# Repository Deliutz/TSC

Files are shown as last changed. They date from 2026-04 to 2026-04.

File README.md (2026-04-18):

# InkTime Smartwatch Project

Proiect hardware pentru realizarea unui smartwatch open-source low-cost, bazat pe microcontrollerul **Nordic nRF52840**, proiectat în **Autodesk Fusion 360 Electronics**.

---

# Diagrama bloc

```text
Baterie LiPo
    |
    v
+------------------+
|   BQ25180YBGR    |
| Charger / PMIC   |
+------------------+
    |
    v
+------------------+
|    RT6160AWSC    |
| Buck-Boost 3.3V  |
+------------------+
    |
    v
+------------------+
|    nRF52840      |
|   MCU + BLE      |
+------------------+
   |      |      |      |      |
   |      |      |      |      |
   |      |      |      |      +-------------------+
   |      |      |      |                          |
   |      |      |      v                          v
   |      |      |  +---------+              +-----------+
   |      |      |  | Buttons |              | TC2030    |
   |      |      |  | 3x GPIO |              | SWD Debug |
   |      |      |  +---------+              +-----------+
   |      |      |
   |      |      +-------------------+
   |      |                          |
   |      v                          v
   |  +-----------+            +------------+
   |  | DRV2605   |----------->| Vibra motor|
   |  | Haptic IC |            +------------+
   |  +-----------+
   |
   +---------------------+
   |                     |
   v                     v
+---------+         +-----------+
| BMA421  |         | MAX17048  |
| IMU     |         | Fuel Gauge|
+---------+         +-----------+
   ^                     ^
   |                     |
   +--------- I2C -------+

```

---

# Bill of Materials (BOM)

| Componenta | Cod | Rol | Interfata |
|---|---|---|---|
| NRF52840_QF | U1 | Microcontroller principal + BLE | SPI / I2C / GPIO |
| BQ25180YBGR | IC1 | Incarcare baterie LiPo / power management | Power / I2C |
| RT6160AWSC | IC9 | Convertor buck-boost 3.3V | Power |
| BMA421 | IC3 | Accelerometru / IMU | I2C |
| DRV2605YZFR | IC2 | Driver feedback haptic | I2C / GPIO |
| MAX17048G+T10 | U3 | Fuel gauge baterie | I2C |
| KH-TYPE-C-16P | J4 | Conector USB-C | USB |
| USBLC6-2SC6Y | D3 | Protectie ESD USB | USB |
| 503480-2400 | J2 | Conector display e-paper | SPI |
| 2450AT18B100E | ANT1 | Antena 2.4 GHz BLE | RF |
| TC2030-IDC | J1 | Conector debugging SWD | SWD |
| SW_UP / SW_ENT / SW_DN | SW_UP, SW_ENT, SW_DN | Input utilizator | GPIO |
| X1 | X1 | Cristal de mare frecventa pentru nRF52840 | Clock |
| X2 32.768kHz | X2 | Cristal RTC / low power clock | Clock |
| SI1308EDL-T1-GE3 | Q3 | MOSFET pentru comutare alimentare | Power / GPIO |
| Q1 | Q1 | MOSFET pentru power switching | Power |
| FTC252012SR47MBCA | L7 | Inductor pentru regulatorul de tensiune | Power |
| MBR0530 | D2, D4, D5 | Diode Schottky pentru protectie / redresare | Power |
| TP_* | TP_3.3V, TP_3V3, TP_BAT_GND, TP_GND, TP_ON, TP_OP, TP_RESET, TP_SCL, TP_SDA, TP_SWDCLK, TP_SWDIO, TP_SWO, TP_VBAT, TP_VREG | Test pads pentru validare si debugging | Test / Debug |

---

# Funcționalitate hardware
Designul este construit în jurul microcontrollerului **nRF52840**, responsabil de:
- comunicația Bluetooth Low Energy;
- citirea senzorilor;
- controlul display-ului e-paper;
- gestionarea butoanelor;
- controlul feedback-ului haptic;
- monitorizarea bateriei.

## Alimentare
- **BQ25180** gestionează încărcarea bateriei LiPo;
- **RT6160** generează tensiunea stabilă de **3.3V**;
- **MAX17048** monitorizează nivelul bateriei.

## Senzori și periferice
- **BMA423** este conectat prin **I2C**;
- display-ul e-paper este conectat prin conectorul FPC;
- **DRV2605** comandă motorul de vibrații;
- USB-C este folosit pentru alimentare și debugging.

---

# Utilizarea pinilor nRF52840
## Magistrală I2C
- SDA → IMU + Fuel Gauge
- SCL → IMU + Fuel Gauge

## SWD
- SWDIO
- SWDCLK
- SWO
- RESET

## GPIO
- Buton UP
- Buton ENTER
- Buton DOWN
- semnale control display
- semnal driver haptic

## SPI
- semnale rutate către conectorul display-ului e-paper

---

# Proces de proiectare

## 1. Schematic
În prima etapă am realizat schema electrică pornind de la modelul oferit pe OCW și folosind exclusiv biblioteca pusă la dispoziție.

Am implementat blocurile:
- LiPo Charger
- DC/DC
- IMU
- SWD
- E-Paper Driver
- Fuel Gauge
- Haptic Driver
- Buttons
- USB-C + ESD

În timpul realizării schemei:
- am modificat valorile componentelor pasive;
- am adăugat condensatoare de decuplare;
- am etichetat semnalele importante;
- am separat schematicul pe blocuri funcționale.

---

## 2. PCB Design
PCB-ul a fost realizat pe baza dimensiunilor mecanice recomandate.

Etapele principale:
- placement TOP pentru componentele critice;
- amplasarea componentelor pasive lângă pinii de alimentare;
- rutare pe mai multe straturi;
- plane dedicate de GND;
- păstrarea zonei antenei liberă;
- alinierea USB-C și a butoanelor cu carcasa.

La final am rulat DRC și am corectat erorile principale.

---

## 3. Model 3D
Modelul 3D include:
- PCB
- baterie
- display
- carcasă

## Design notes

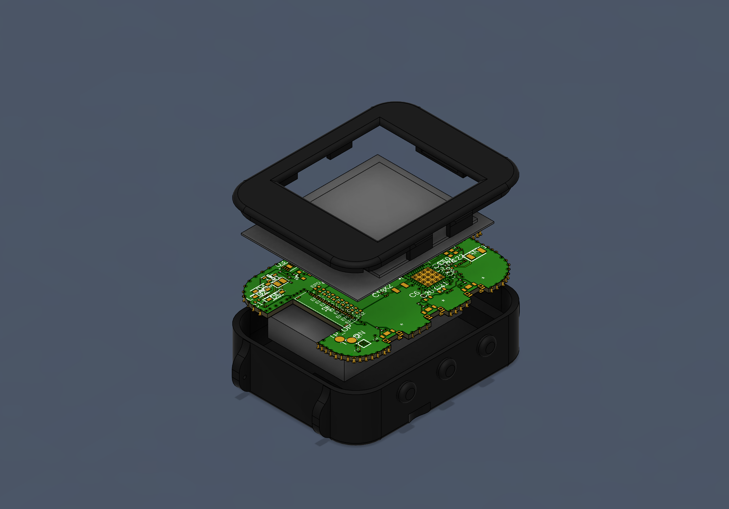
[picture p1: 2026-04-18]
Images/explozie_finala.png

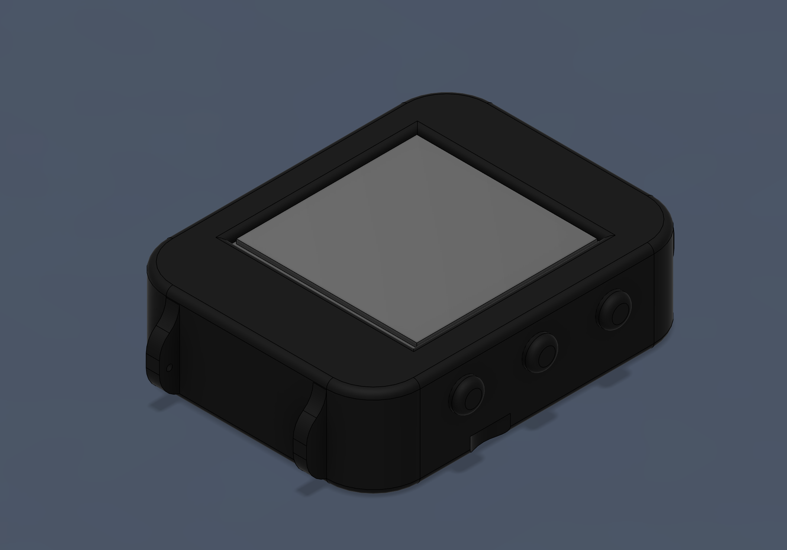
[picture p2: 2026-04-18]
Images/poza_carcasa_finala.png

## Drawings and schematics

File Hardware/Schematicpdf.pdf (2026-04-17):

# LiPo Charger

# DC/DC

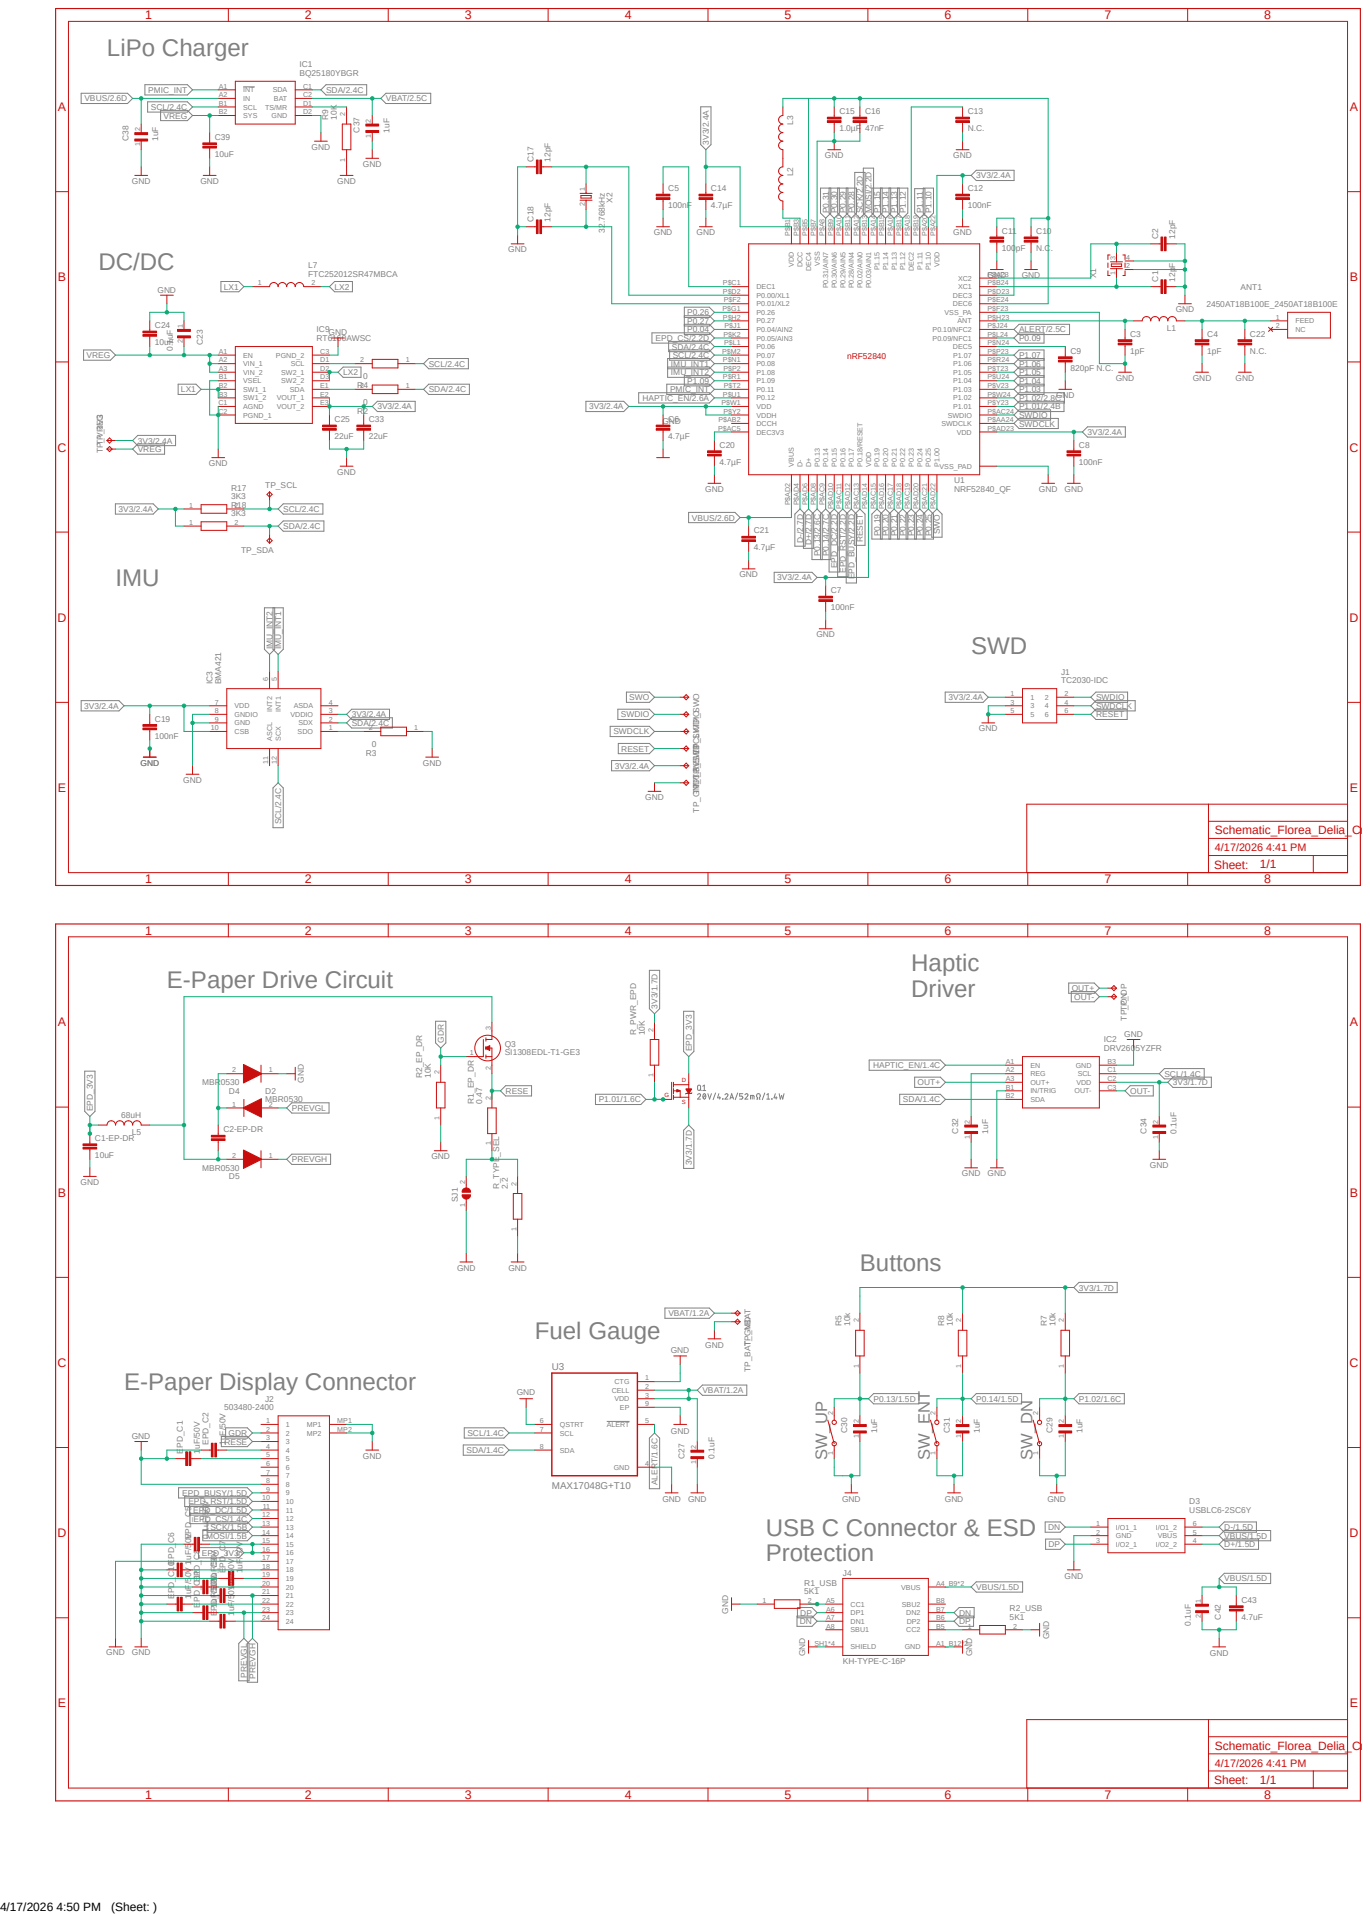
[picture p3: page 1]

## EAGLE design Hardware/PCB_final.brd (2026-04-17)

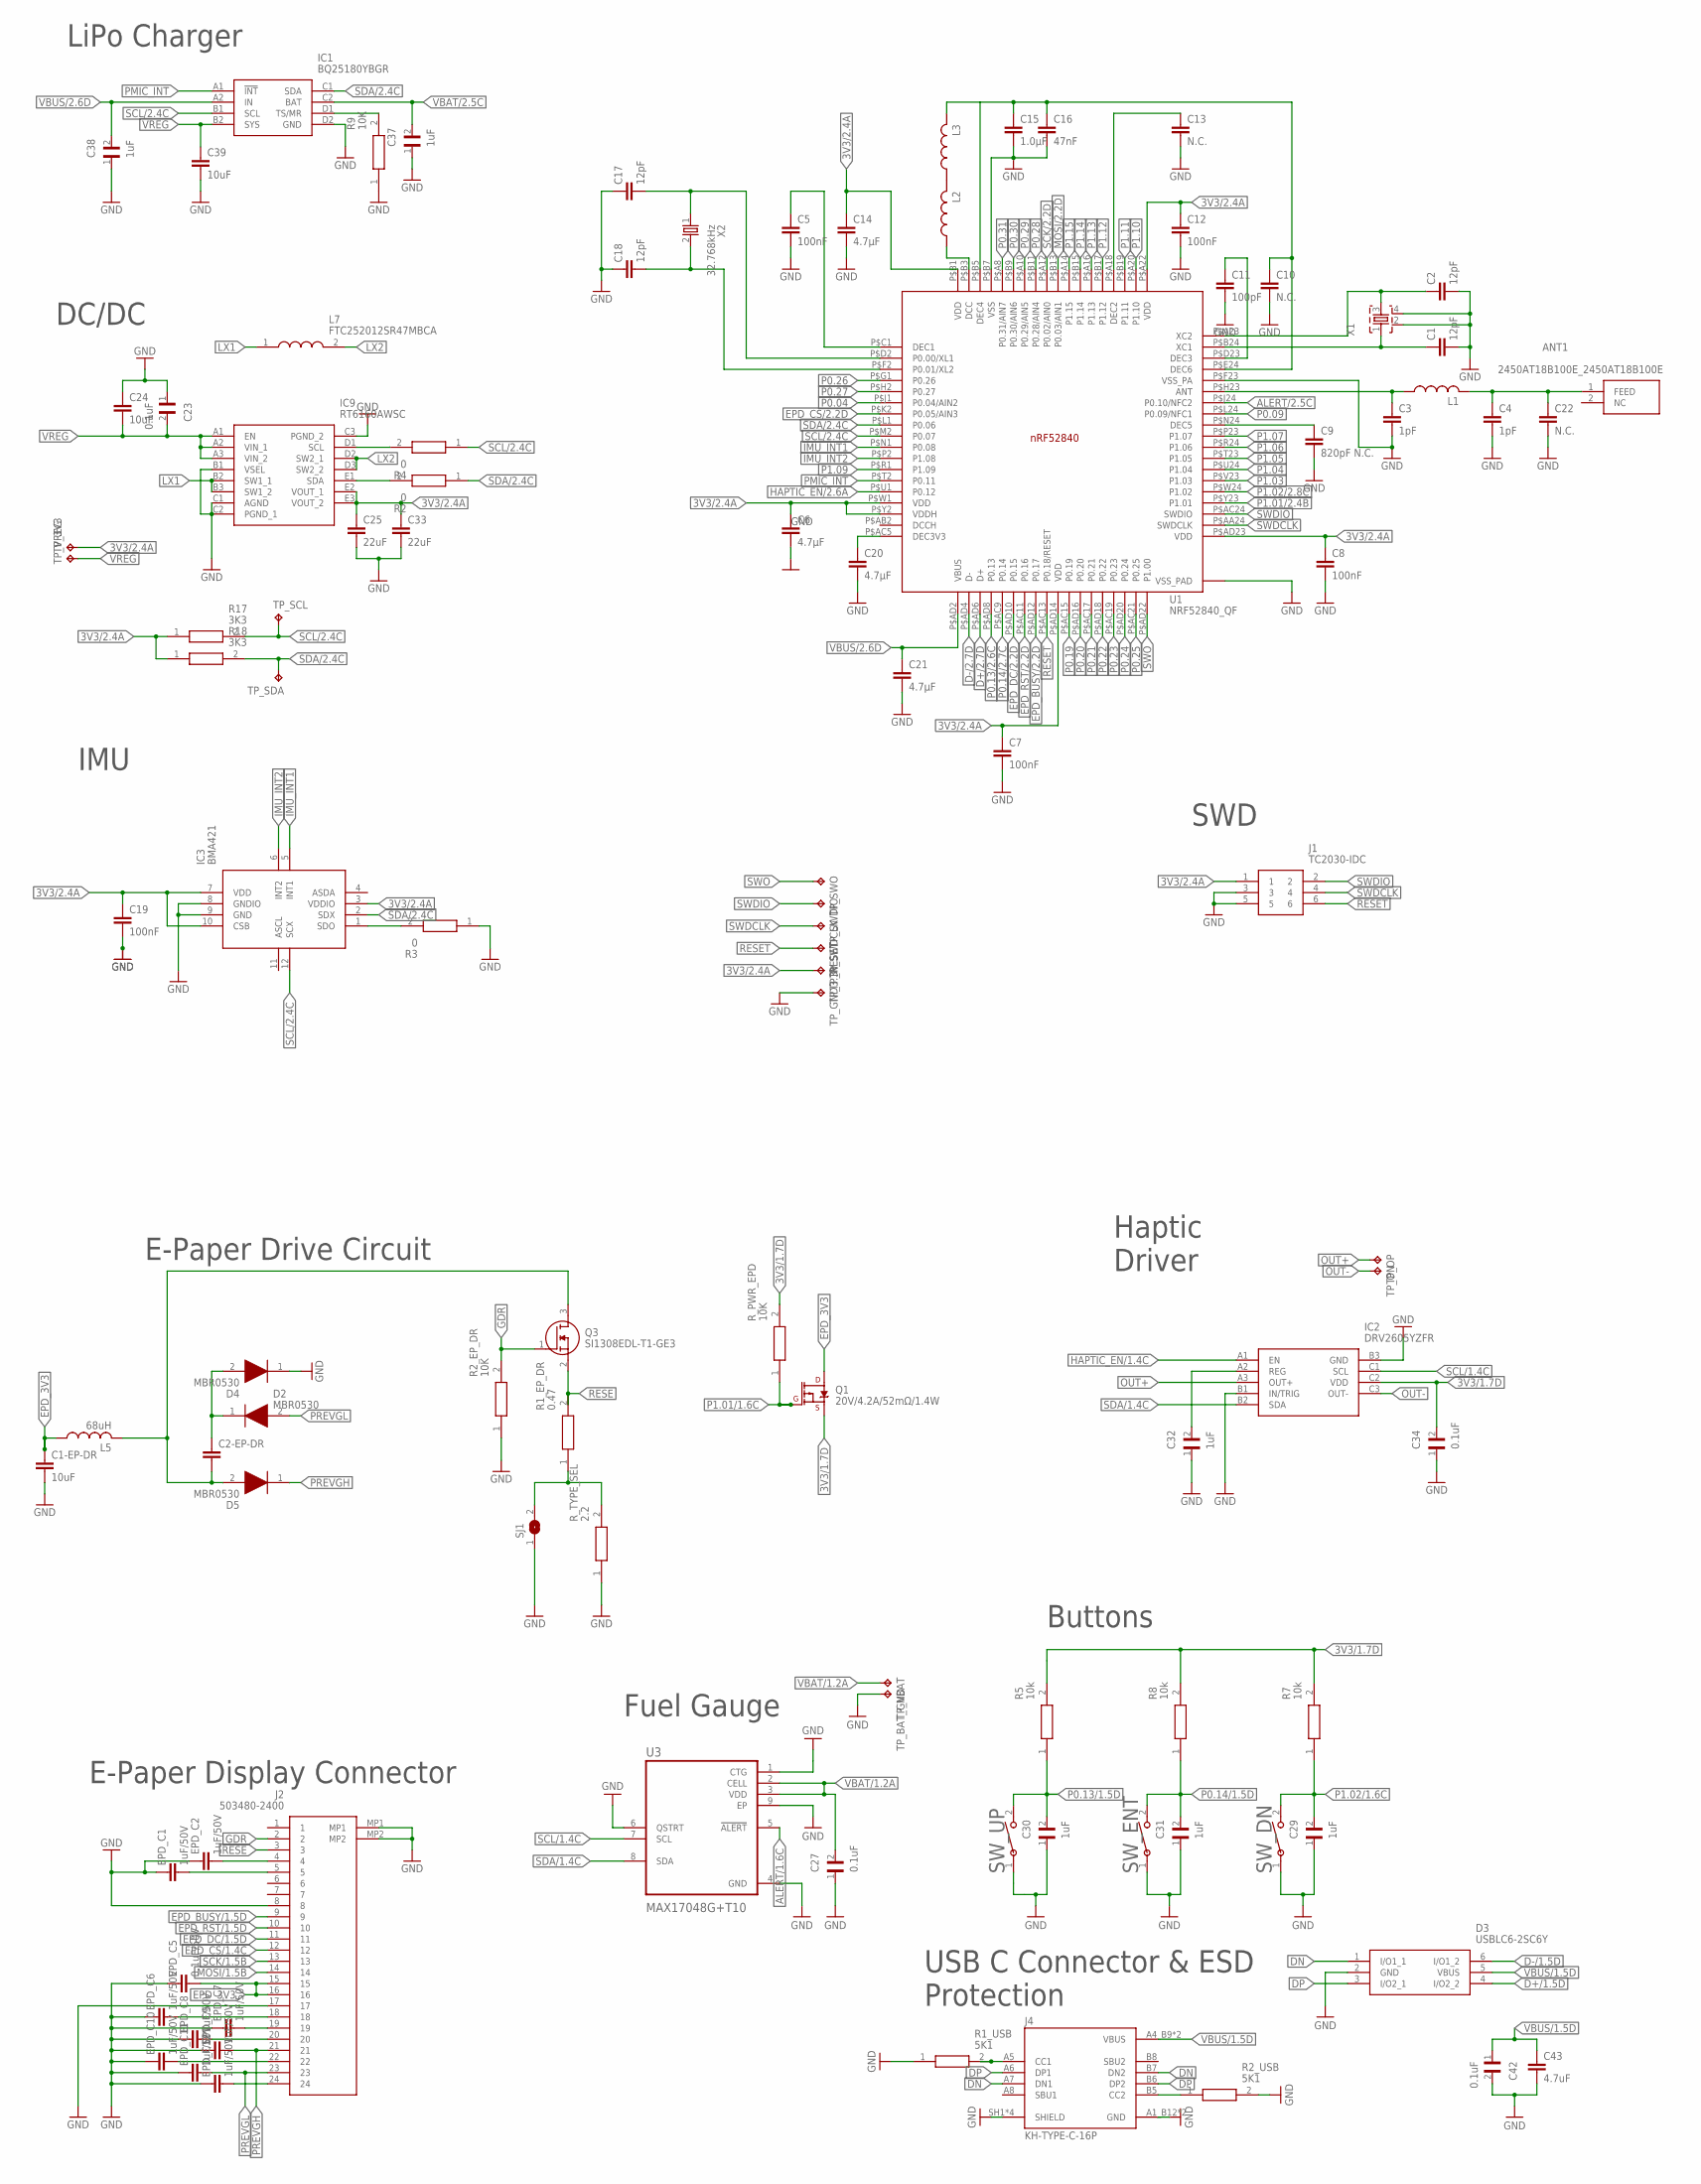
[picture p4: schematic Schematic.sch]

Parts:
ANT1: 2450AT18B100E_2450AT18B100E; 2450AT18B100E_ANTC3216X140N
C1, C2, C17, C18: 12pF; NORDIC_NRF_3_RESC0201_L
C1-EP-DR, C24, C39: 10uF; NORDIC_NRF_3_RESC0201_L
C2-EP-DR: NORDIC_NRF_3_CAPACITOR_0201_L; NORDIC_NRF_3_RESC0201_L
C3, C4: 1pF; NORDIC_NRF_3_RESC0201_L
C5, C7, C8, C12, C19: 100nF; NORDIC_NRF_3_RESC0201_L
C6: 4.7µF; NORDIC_NRF_3_RESC0201_L
C9: 820pF N.C.; NORDIC_NRF_3_RESC0201_L
C10, C13, C22: N.C.; NORDIC_NRF_3_RESC0201_L
C11: 100pF; NORDIC_NRF_3_RESC0201_L
C14, C20, C21: 4.7µF; ESP32_C6_LIBRARY_1_ESP32_WROVER_EAGLE-LTSPICE_C0402
C15: 1.0µF; NORDIC_NRF_3_RESC0201_L
C16: 47nF; NORDIC_NRF_3_RESC0201_L
C23, C34: 0.1uF; GRM011R60J152KE01L_2_CAPC0201X13N
C25, C33: 22uF; NORDIC_NRF_3_RESC0201_L
C27, C42: 0.1uF; GRM011R60J152KE01L_1_0201
C29, C30, C31: 1uF; GRM011R60J152KE01L_1_0201
C32, C37, C38: 1uF; GRM011R60J152KE01L_2_CAPC0201X13N
C43: 4.7uF; NORDIC_NRF_3_RESC0201_L
D2, D4, D5: MBR0530; ESP32_C6_LIBRARY_5_SOD3716X135N
D3: USBLC6-2SC6Y; ESP32_C6_LIBRARY_3_SOT95P280X145-6N
EPD_C1, EPD_C2, EPD_C6, EPD_C7, EPD_C8, EPD_C9, EPD_C10, EPD_C11, EPD_C12: 1uF/50V; PERFECT_0402_0402
EPD_C5: 0.1uF/50V; PERFECT_0402_0402
IC1: BQ25180YBGR; BQ25180YBGR_BGA8C40P2X4_100X155X50
IC2: DRV2605YZFR; DRV2605YZFR_BGA9C50P3X3_144X144X62
IC3: BMA421; BMA423_BMA423
IC9: RT6160AWSC; RT6160AWSC_BGA15C40P3X5_140X230X60
J1: TC2030-IDC; TC2030-IDC_TC2030IDC
J2: 503480-2400; 503480-2400_5034802400
J4: KH-TYPE-C-16P; KH-TYPE-C-16P_KINGHELM_KH-TYPE-C-16P
L1, L2, L3: NORDIC_NRF_2_INDUCTOR_0402_L; NORDIC_NRF_2_RESC0402_L
L5: 68uH; NORDIC_NRF_2_RESC0402_L
L7: FTC252012SR47MBCA; MLP2016SR47MT0S1_INDC2016X100N
Q1: 20V/4.2A/52mΩ/1.4W; ESP32_C6_LIBRARY_4_ESP32_C6_LIBRARY_4_ESP32_C6_LIBRARY_4_ES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
Q3: SI1308EDL-T1-GE3; ESP32_C6_LIBRARY_6_SOT65P210X110-3N
R1_EP_DR: 0.47; ERA-1AEB3401C_0201
R1_USB, R2_USB: 5K1; CPF0201D7K68C1_0201
R2, R4: 0; ERA-1AEB3401C_0201
R2_EP_DR, R9: 10K; ERA-1AEB3401C_0201
R3: 0; CPF0201D7K68C1_0201
R5, R7, R8: 10k; CPF0201D7K68C1_0201
R17, R18: 3K3; ERA-1AEB3401C_0201
R_PWR_EPD: 10K; ERA-1AEB3401C_0201
R_TYPE_SEL: 2.2; ERA-1AEB3401C_0201
SJ1: ESP32_C6_LIBRARY_7_JUMPER_SJ
SW_DN: 2025-10-22_07-23-44_LIBRARY_EVP-AKE31ASW_EVP-AKE3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; 2025-10-22_07-23-44_LIBRARY_SW_EVP-AKE31A_PAN
SW_ENT: 2025-10-22_07-23-44_LIBRARY_EVP-AKE31ASW_EVP-AKE3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; 2025-10-22_07-23-44_LIBRARY_SW_EVP-AKE31A_PAN
SW_UP: 2025-10-22_07-23-44_LIBRARY_EVP-AKE31ASW_EVP-AKE3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; 2025-10-22_07-23-44_LIBRARY_SW_EVP-AKE31A_PAN
TP_3.3V, TP_3V3: HECTOR_WATCH_1_TPTP20R; HECTOR_WATCH_1_TP20R
TP_BAT_GND: HECTOR_WATCH_1_TPTP20R; HECTOR_WATCH_1_TP20R
TP_GND: HECTOR_WATCH_1_TPTP20R; HECTOR_WATCH_1_TP20R
TP_ON: HECTOR_WATCH_1_TPTP20R; HECTOR_WATCH_1_TP20R
TP_OP: HECTOR_WATCH_1_TPTP20R; HECTOR_WATCH_1_TP20R
TP_RESET: HECTOR_WATCH_1_TPTP20R; HECTOR_WATCH_1_TP20R
TP_SCL: HECTOR_WATCH_1_TPTP20R; HECTOR_WATCH_1_TP20R
TP_SDA: HECTOR_WATCH_1_TPTP20R; HECTOR_WATCH_1_TP20R
TP_SWDCLK: HECTOR_WATCH_1_TPTP20R; HECTOR_WATCH_1_TP20R
TP_SWDIO: HECTOR_WATCH_1_TPTP20R; HECTOR_WATCH_1_TP20R
TP_SWO: HECTOR_WATCH_1_TPTP20R; HECTOR_WATCH_1_TP20R
TP_VBAT: HECTOR_WATCH_1_TPTP20R; HECTOR_WATCH_1_TP20R
TP_VREG: HECTOR_WATCH_1_TPTP20R; HECTOR_WATCH_1_TP20R
U1: NRF52840_QF; NORDIC_NRF_4_AQFN50P700X700X85_HS-74N
U3: MAX17048G+T10; ESP32_C6_LIBRARY_SON50P200X200X80-9N
X1: NORDIC_NRF_XTAL_32MHZ; NORDIC_NRF_BT-XTAL_2016_N
X2: 32.768kHz; NORDIC_NRF_1_XTAL_3215_N

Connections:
3V3/1.7D: C34.2, IC2.C2 (VDD), Q1.2 (S), R5.2, R7.2, R8.2, R_PWR_EPD.2
3V3/2.4A: C6.1, C7.1, C8.1, C12.1, C14.1, C19.1, C25.1, C33.1, IC3.3 (VDDIO), IC3.7 (VDD), IC3.10 (CSB), IC9.E2 (VOUT_1), IC9.E3 (VOUT_2), J1.1, R17.1, R18.1, TP_3.3V.TP, TP_3V3.TP, U1.P$A22 (VDD), U1.P$AD14 (VDD), U1.P$AD23 (VDD), U1.P$B1 (VDD), U1.P$W1 (VDD), U1.P$Y2 (VDDH)
ALERT/1.6C: U3.5 (!ALERT)
ALERT/2.5C: U1.P$J24 (P0.10/NFC2)
D+/1.5D: D3.4 (I/O2_2)
D+/2.7D: U1.P$AD6 (D+)
D-/1.5D: D3.6 (I/O1_2)
D-/2.7D: U1.P$AD4 (D-)
DN: D3.1 (I/O1_1), J4.A7 (DN1), J4.B7 (DN2)
DP: D3.3 (I/O2_1), J4.A6 (DP1), J4.B6 (DP2)
EPD_3V3: C1-EP-DR.1, EPD_C5.2, J2.15, J2.16, L5.1, Q1.3 (D)
EPD_BUSY/1.5D: J2.9
EPD_BUSY/2.2D: U1.P$AD12 (P0.17)
EPD_CS/1.4C: J2.12
EPD_CS/2.2D: U1.P$K2 (P0.05/AIN3)
EPD_DC/1.5D: J2.11
EPD_DC/2.2D: U1.P$AD10 (P0.15)
EPD_RST/1.5D: J2.10
EPD_RST/2.2D: U1.P$AC11 (P0.16)
GDR: J2.2, Q3.1 (G), R2_EP_DR.2
GND: C1.2, C1-EP-DR.2, C2.2, C3.2, C4.2, C5.2, C6.2, C7.2, C8.2, C9.2, C10.2, C11.2, C12.2, C13.2, C14.2, C15.2, C16.2, C17.1, C18.1, C19.2, C20.2, C21.2, C22.2, C23.1, C24.1, C25.2, C27.1, C29.1, C30.1, C31.1, C32.1, C33.2, C34.1, C37.1, C38.1, C39.2, C42.2, C43.2, D3.2 (GND), D4.1 (K), EPD_C1.1, EPD_C2.1, EPD_C5.1, EPD_C6.1, EPD_C7.1, EPD_C8.1, EPD_C9.1, EPD_C10.1, EPD_C11.1, EPD_C12.1, IC1.D2 (GND), IC2.B1 (IN/TRIG), IC2.B3 (GND), IC3.8 (GNDIO), IC3.9 (GND), IC9.B1 (VSEL), IC9.C1 (AGND), IC9.C2 (PGND_1), IC9.C3 (PGND_2), J1.3, J1.5, J2.8, J2.17, J2.MP1, J2.MP2, J4.A1_B12 (GND), J4.A12_B1 (GND), J4.SH1 (SHIELD), J4.SH2 (SHIELD), J4.SH3 (SHIELD), J4.SH4 (SHIELD), R1_USB.1, R2_EP_DR.1, R2_USB.2, R3.1, R9.1, R_TYPE_SEL.1, SJ1.1, SW_DN.1, SW_ENT.1, SW_UP.1, TP_BAT_GND.TP, TP_GND.TP, U1.P$74 (VSS_PAD), U1.P$75 (VSS_PAD), U1.P$76 (VSS_PAD), U1.P$77 (VSS_PAD), U1.P$78 (VSS_PAD), U1.P$79 (VSS_PAD), U1.P$80 (VSS_PAD), U1.P$81 (VSS_PAD), U1.P$82 (VSS_PAD), U1.P$83 (VSS_PAD), U1.P$84 (VSS_PAD), U1.P$85 (VSS_PAD), U1.P$86 (VSS_PAD), U1.P$87 (VSS_PAD), U1.P$88 (VSS_PAD), U1.P$89 (VSS_PAD), U1.P$90 (VSS_PAD), U1.P$B7 (VSS), U1.P$F23 (VSS_PA), U3.1 (CTG), U3.4 (GND), U3.6 (QSTRT), U3.9 (EP), X1.2, X1.4
HAPTIC_EN/1.4C: IC2.A1 (EN)
HAPTIC_EN/2.6A: U1.P$U1 (P0.12)
IMU_INT1: IC3.5 (INT1), U1.P$N1 (P0.08)
IMU_INT2: IC3.6 (INT2), U1.P$P2 (P1.08)
LX1: IC9.B2 (SW1_1), IC9.B3 (SW1_2), L7.1
LX2: IC9.D2 (SW2_1), IC9.D3 (SW2_2), L7.2
MOSI/1.5B: J2.14
MOSI/2.2D: U1.P$B13 (P0.03/AIN1)
unnamed: IC1.D1 (TS/MR), R9.2
unnamed: L2.2, L3.1
unnamed: C10.1, C15.1, C16.1, L3.2, U1.P$E24 (DEC6)
unnamed: ANT1.1 (FEED), C4.1, C22.1, L1.2
unnamed: IC9.D1 (SCL), R4.2
unnamed: C2-EP-DR.2, D5.2 (A), L5.2, Q3.3 (D)
unnamed: IC9.E1 (SDA), R2.2
unnamed: C2-EP-DR.1, D2.1 (K), D4.2 (A)
unnamed: IC3.1 (SDO), R3.2
unnamed: EPD_C2.2, J2.4
unnamed: C32.2, IC2.A2 (REG)
unnamed: EPD_C1.2, J2.5
unnamed: C20.1, U1.P$AC5 (DEC3V3)
unnamed: C5.1, U1.P$C1 (DEC1)
unnamed: C17.2, U1.P$D2 (P0.00/XL1), X2.1
unnamed: C18.2, U1.P$F2 (P0.01/XL2), X2.2
unnamed: R1_EP_DR.1, R_TYPE_SEL.2, SJ1.2
unnamed: L2.1, U1.P$B3 (DCC)
unnamed: J4.A5 (CC1), R1_USB.2
unnamed: C3.1, L1.1, U1.P$H23 (ANT)
unnamed: C9.1, U1.P$N24 (DEC5)
unnamed: C1.1, U1.P$B24 (XC1), X1.1
unnamed: C2.1, U1.P$A23 (XC2), X1.3
unnamed: C11.1, U1.P$D23 (DEC3)
unnamed: C13.1, U1.P$A18 (DEC2)
unnamed: EPD_C6.2, J2.18
unnamed: EPD_C7.2, J2.19
unnamed: EPD_C8.2, J2.20
unnamed: J4.B5 (CC2), R2_USB.1
unnamed: EPD_C10.2, J2.22
unnamed: EPD_C12.2, J2.24
OUT+: IC2.A3 (OUT+), TP_OP.TP
OUT-: IC2.C3 (OUT-), TP_ON.TP
P0.04: U1.P$J1 (P0.04/AIN2)
P0.09: U1.P$L24 (P0.09/NFC1)
P0.13/1.5D: C30.2, R5.1, SW_UP.2
P0.13/2.6C: U1.P$AD8 (P0.13)
P0.14/1.5D: C31.2, R8.1, SW_ENT.2
P0.14/2.7C: U1.P$AC9 (P0.14)
P0.19: U1.P$AC15 (P0.19)
P0.20: U1.P$AD16 (P0.20)
P0.21: U1.P$AC17 (P0.21)
P0.22: U1.P$AD18 (P0.22)
P0.23: U1.P$AC19 (P0.23)
P0.24: U1.P$AD20 (P0.24)
P0.25: U1.P$AC21 (P0.25)
P0.26: U1.P$G1 (P0.26)
P0.27: U1.P$H2 (P0.27)
P0.28: U1.P$B11 (P0.28/AIN4)
P0.29: U1.P$A10 (P0.29/AIN5)
P0.30: U1.P$B9 (P0.30/AIN6)
P0.31: U1.P$A8 (P0.31/AIN7)
P1.01/1.6C: Q1.1 (G), R_PWR_EPD.1
P1.01/2.4B: U1.P$Y23 (P1.01)
P1.02/1.6C: C29.2, R7.1, SW_DN.2
P1.02/2.8C: U1.P$W24 (P1.02)
P1.03: U1.P$V23 (P1.03)
P1.04: U1.P$U24 (P1.04)
P1.05: U1.P$T23 (P1.05)
P1.06: U1.P$R24 (P1.06)
P1.07: U1.P$P23 (P1.07)
P1.09: U1.P$R1 (P1.09)
P1.10: U1.P$A20 (P1.10)
P1.11: U1.P$B19 (P1.11)
P1.12: U1.P$B17 (P1.12)
P1.13: U1.P$A16 (P1.13)
P1.14: U1.P$B15 (P1.14)
P1.15: U1.P$A14 (P1.15)
PMIC_INT: IC1.A1 (!INT), U1.P$T2 (P0.11)
PREVGH: D5.1 (K), EPD_C9.2, J2.21
PREVGL: D2.2 (A), EPD_C11.2, J2.23
RESE: J2.3, Q3.2 (S), R1_EP_DR.2
RESET: J1.6, TP_RESET.TP, U1.P$AC13 (P0.18/RESET)
SCK/1.5B: J2.13
SCK/2.2D: U1.P$A12 (P0.02/AIN0)
SCL/1.4C: IC2.C1 (SCL), U3.7 (SCL)
SCL/2.4C: IC1.B1 (SCL), IC3.12 (SCX), R4.1, R17.2, TP_SCL.TP, U1.P$M2 (P0.07)
SDA/1.4C: IC2.B2 (SDA), U3.8 (SDA)
SDA/2.4C: IC1.C1 (SDA), IC3.2 (SDX), R2.1, R18.2, TP_SDA.TP, U1.P$L1 (P0.06)
SWDCLK: J1.4, TP_SWDCLK.TP, U1.P$AA24 (SWDCLK)
SWDIO: J1.2, TP_SWDIO.TP, U1.P$AC24 (SWDIO)
SWO: TP_SWO.TP, U1.P$AD22 (P1.00)
VBAT/1.2A: C27.2, TP_VBAT.TP, U3.2 (CELL), U3.3 (VDD)
VBAT/2.5C: C37.2, IC1.C2 (BAT)
VBUS/1.5D: C42.1, C43.1, D3.5 (VBUS), J4.A4_B9 (VBUS), J4.A9_B4 (VBUS)
VBUS/2.6D: C21.1, C38.2, IC1.A2 (IN), U1.P$AD2 (VBUS)
VREG: C23.2, C24.2, C39.1, IC1.B2 (SYS), IC9.A1 (EN), IC9.A2 (VIN_1), IC9.A3 (VIN_2), TP_VREG.TP

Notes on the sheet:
LiPo Charger
DC/DC
IMU
SWD
E-Paper Drive Circuit
Haptic Driver
E-Paper Display Connector
Fuel Gauge
Buttons
USB C Connector & ESD Protection

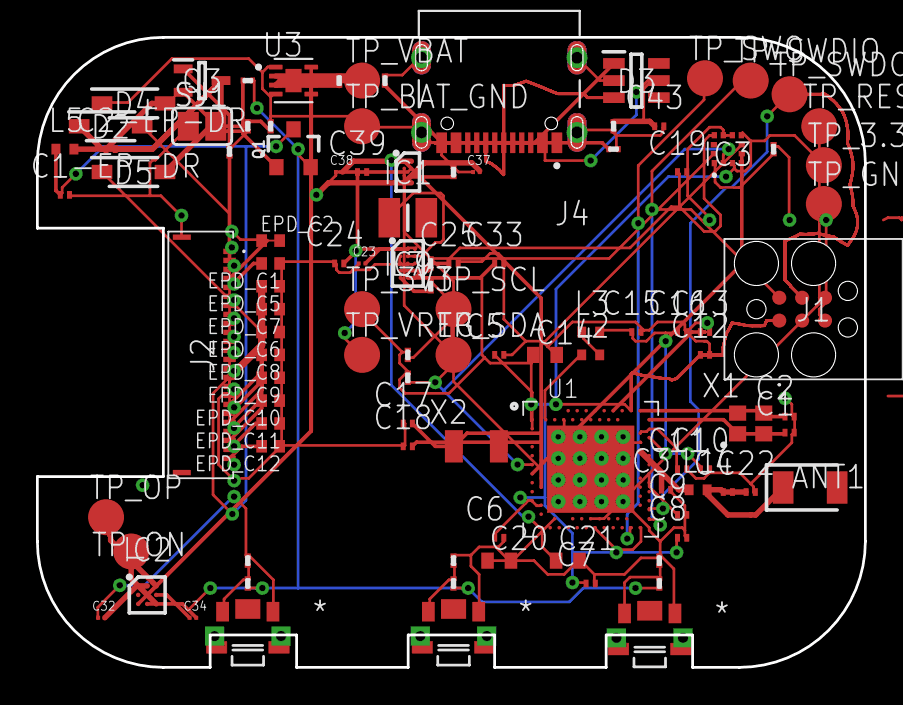
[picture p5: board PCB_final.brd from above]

Board: 4 copper layers, 46.0 x 35.0 mm, 105 parts (0 on the bottom side), 65 nets.

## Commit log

2026-04-10 Create README with project overview and design details
    Added detailed documentation for schematic, PCB design, and 3D model of the smartwatch project.
2026-04-18 README.md
    Updated block diagram and BOM for clarity and accuracy.

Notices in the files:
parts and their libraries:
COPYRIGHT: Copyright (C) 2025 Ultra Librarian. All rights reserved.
